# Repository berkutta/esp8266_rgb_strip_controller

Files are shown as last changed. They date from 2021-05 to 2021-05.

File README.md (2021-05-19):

ESP8266 RGB Strip Controller
================

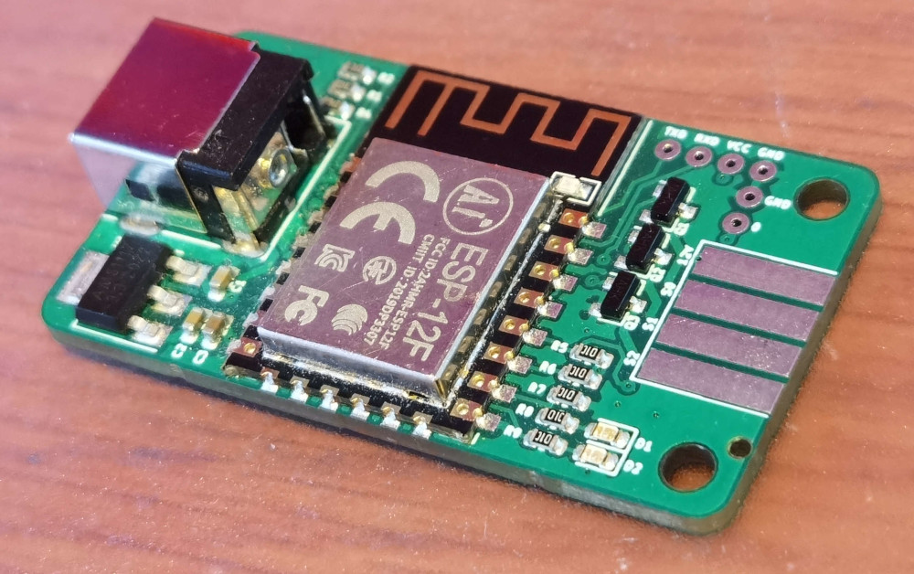
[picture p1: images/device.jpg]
device


This is a simple ESP8266 based RGB Strip Controller for common color LED strips. It is designed for LED strips which have a common +12V and a negative Pin for each color. But it can also be used to switch single color LED strips or other appliances which don't exceed the current of 6A per Channel.

The Controller can be powered by a 12V DC Jack. Center positive.

### Programming

Programming is possible with `esptool` and a standard 3.3V UART Port. Connect TX and RX crossed with your UART Port, bridge the GPIO0 pad to GND and connect Power to it. Afterwards you can loose the GPIO0 to GND connection and let `esptool` upload the Firmware.

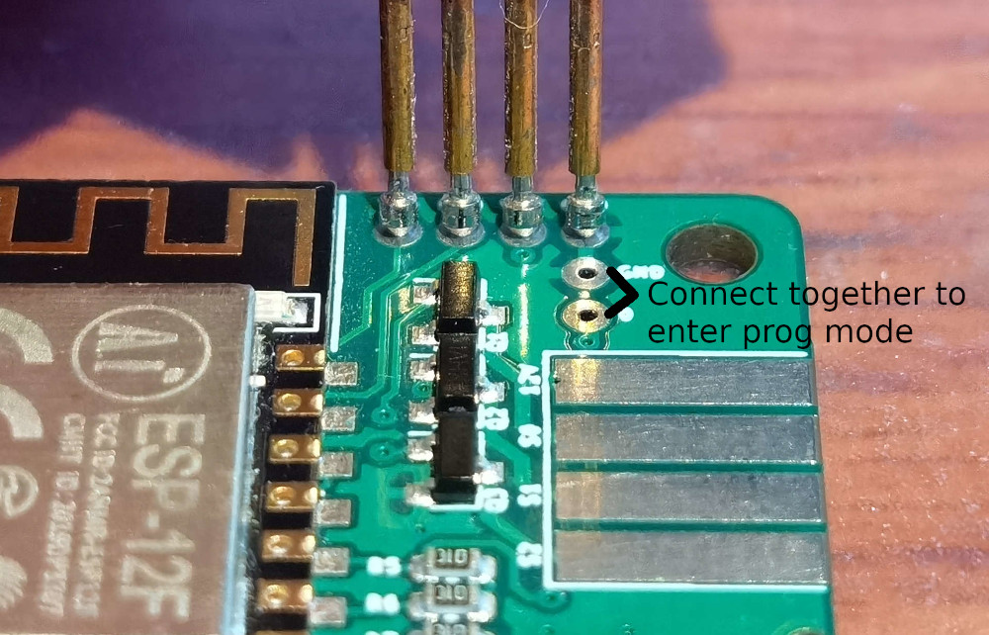
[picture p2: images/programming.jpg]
programming


### Enclosure

In the folder `enclosure` are 3D files for a 3D printable enclosure.

### Assembly

Except the DC Jack all parts are available in the Assembly Service of JLCPCB. The DC Jack can be ordered together with the JLCPCB Order on LCSC.

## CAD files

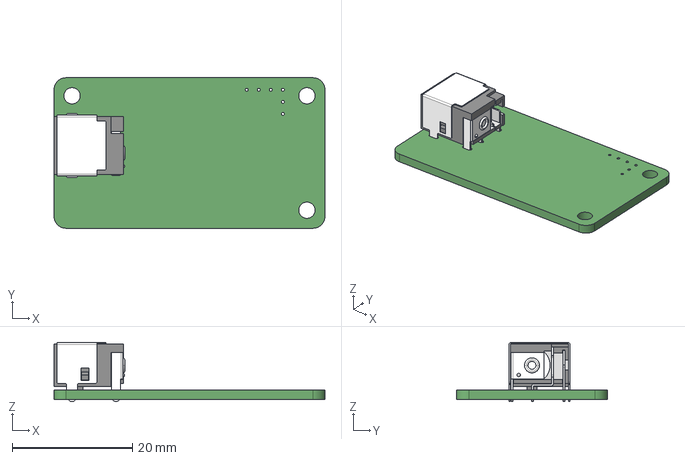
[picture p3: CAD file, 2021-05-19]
esp8266_rgb_strip_controller.step
45.0 x 25.0 x 9.80 mm

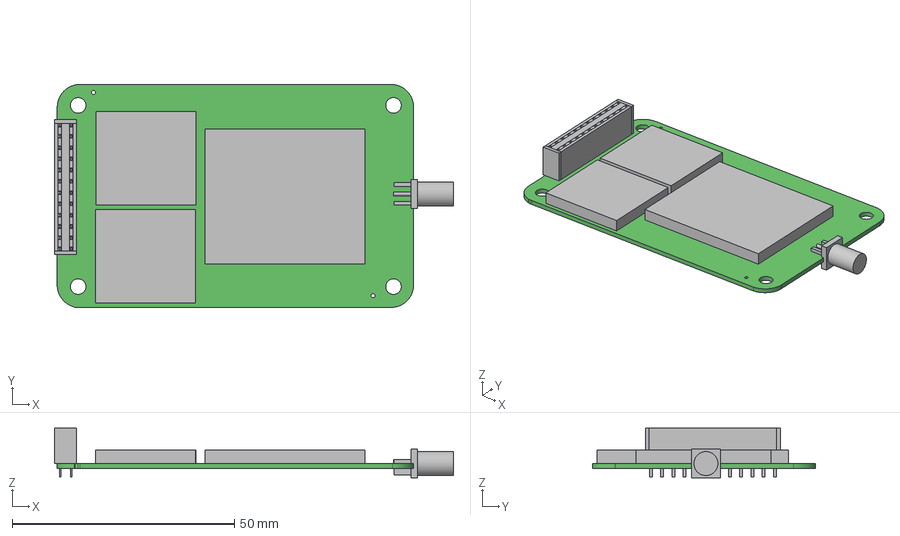
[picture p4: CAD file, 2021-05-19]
footprints/3 D file.step
89.8 x 50.3 x 11.2 mm
Board
Extruded x 64

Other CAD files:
footprints/3D file.step

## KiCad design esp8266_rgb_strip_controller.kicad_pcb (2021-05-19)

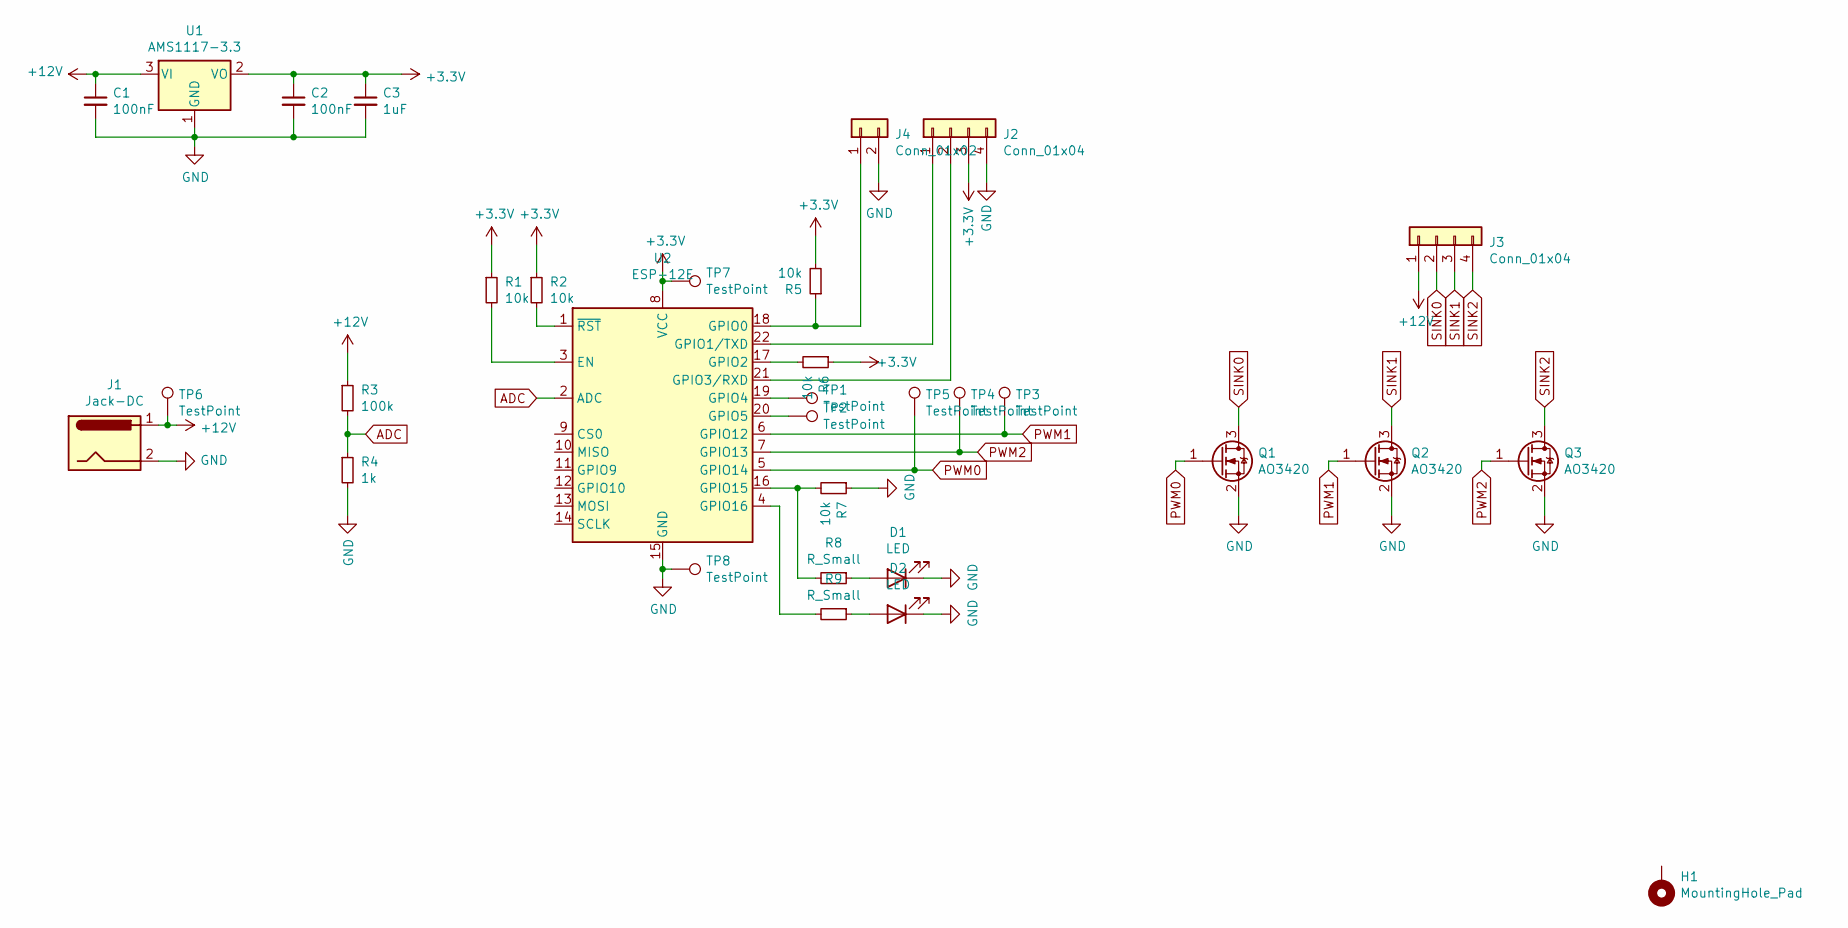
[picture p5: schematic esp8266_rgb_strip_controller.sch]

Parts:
C1, C2: 100nF; C_0603_1608Metric; LCSC C14663
C3: 1uF; C_0603_1608Metric; LCSC C15849
D1: LED; LED_0603_1608Metric; LCSC C72041
D2: LED; LED_0603_1608Metric; LCSC C72043
H1: MountingHole_Pad; MountingHole_2.7mm_M2.5
J1: Jack-DC; pj-051b; LCSC C388627
J2: Conn_01x04; prog_header
J3: Conn_01x04; PinHeader_1x04_P2.54mm_Vertical
J4: Conn_01x02; prog_boot_header
Q1, Q2, Q3: AO3420; SOT-23; LCSC C181095
R1, R2, R5, R6, R7: 10k; R_0603_1608Metric; LCSC C25804
R3: 100k; R_0603_1608Metric; LCSC C25803
R4: 1k; R_0603_1608Metric; LCSC C21190
R8, R9: R_Small; R_0603_1608Metric; LCSC C25804
TP1, TP2, TP3, TP4, TP5, TP6, TP7, TP8: TestPoint; TestPoint_Pad_D1.0mm
U1: AMS1117-3.3; TO-252-2; LCSC C6186
U2: ESP-12E; LCSC C82891

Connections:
+3V3: C2.1, C3.1, J2.3, R1.1, R2.1, R5.2, R6.1, TP7.1, U1.2 (VO), U2.8 (VCC)
+12V: C1.1, J1.1, J3.1, R3.1, TP6.1, U1.3 (VI)
ADC: R3.2, R4.1, U2.2 (ADC)
GND: C1.2, C2.2, C3.2, D1.1 (K), D2.1 (K), J1.2, J2.4, J4.2, Q1.2 (S), Q2.2 (S), Q3.2 (S), R4.2, R7.1, TP8.1, U1.1 (GND), U2.15 (GND)
unnamed: D1.2 (A), R8.1
unnamed: D2.2 (A), R9.1
unnamed: J2.1, U2.22 (GPIO1/TXD)
unnamed: J2.2, U2.21 (GPIO3/RXD)
unnamed: J4.1, R5.1, U2.18 (GPIO0)
unnamed: R1.2, U2.3 (EN)
unnamed: R2.2, U2.1 (~RST)
unnamed: R6.2, U2.17 (GPIO2)
unnamed: R7.2, R8.2, U2.16 (GPIO15)
unnamed: R9.2, U2.4 (GPIO16)
unnamed: TP1.1, U2.19 (GPIO4)
unnamed: TP2.1, U2.20 (GPIO5)
PWM0: Q1.1 (G), TP5.1, U2.5 (GPIO14)
PWM1: Q2.1 (G), TP3.1, U2.6 (GPIO12)
PWM2: Q3.1 (G), TP4.1, U2.7 (GPIO13)
SINK0: J3.2, Q1.3 (D)
SINK1: J3.3, Q2.3 (D)
SINK2: J3.4, Q3.3 (D)

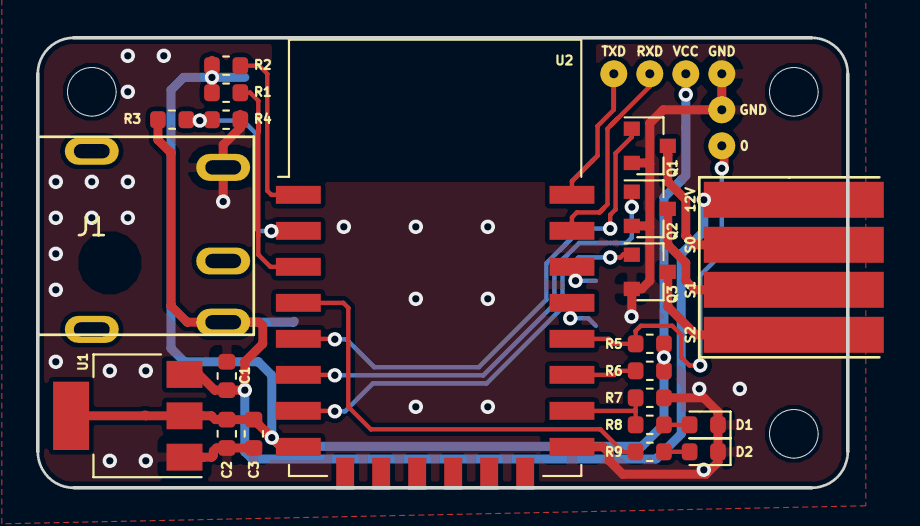
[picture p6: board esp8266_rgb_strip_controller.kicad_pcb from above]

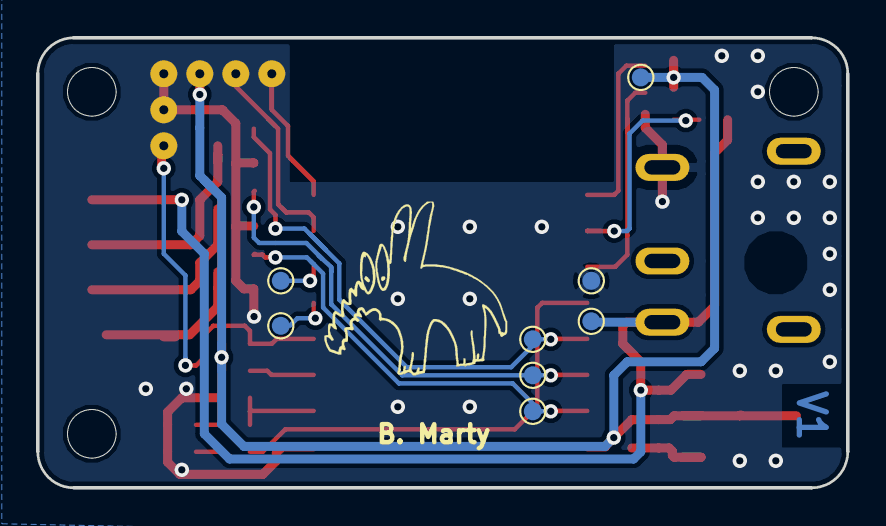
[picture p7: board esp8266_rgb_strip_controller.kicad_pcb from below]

Board: 2 copper layers, 45.0 x 25.0 mm, 34 parts (8 on the bottom side), 22 nets.

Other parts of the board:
H2, H3: MountingHole_Pad; MountingHole_2.7mm_M2.5
